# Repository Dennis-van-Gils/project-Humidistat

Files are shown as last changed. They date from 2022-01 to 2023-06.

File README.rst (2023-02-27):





Humidistat
==========
*A Physics of Fluids project.*

This project concerns an Arduino powered controller with a graphical user-interface in Python to regulate the relative humidity inside of a chamber. It does so by controlling two air lines, one with moist air and the other with dry air, using solenoid valves. The temperature, pressure and relative humidity of the chamber and the optional upstream mixing vessel are measured and can be logged over time.

- Github: https://github.com/Dennis-van-Gils/project-Humidistat

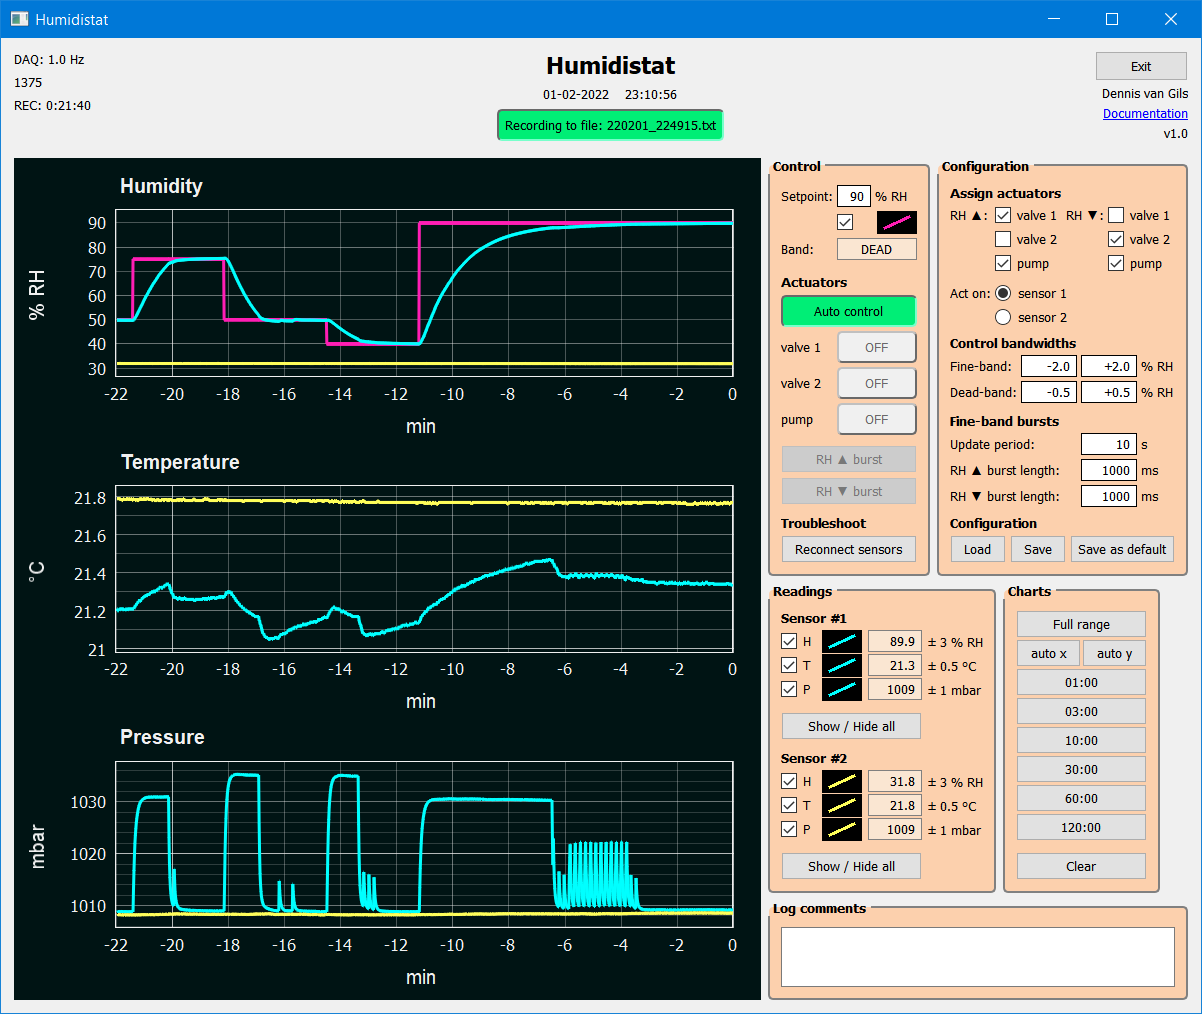
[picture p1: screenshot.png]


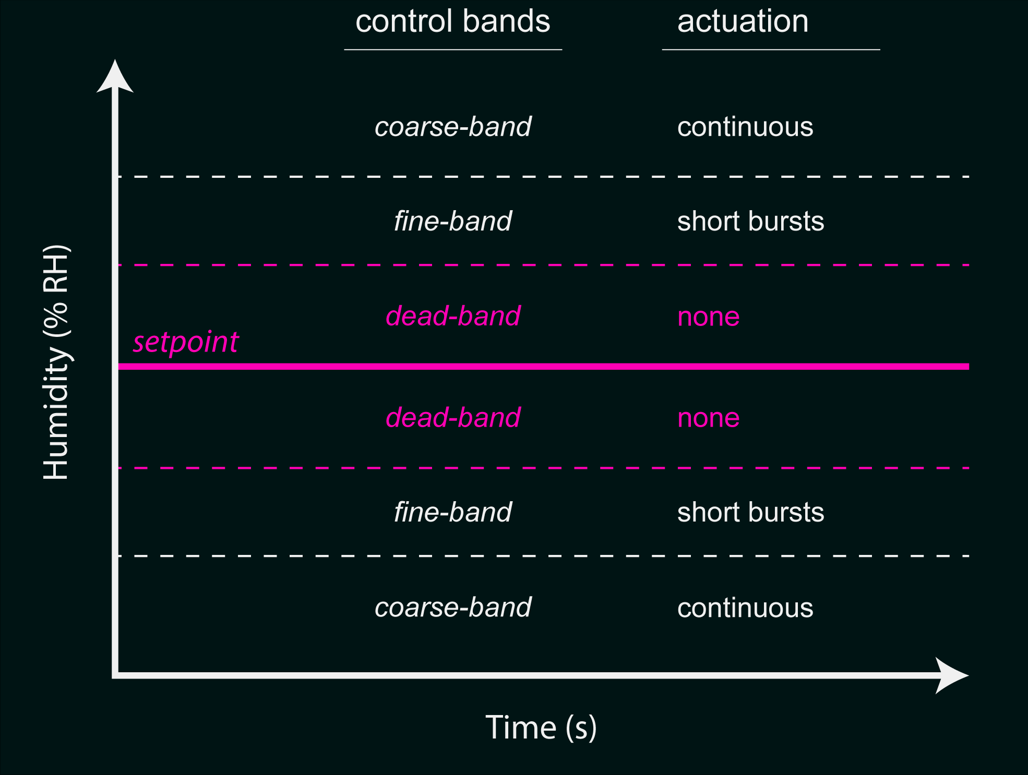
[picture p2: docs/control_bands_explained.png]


Hardware
========
* Adafruit #3857: Adafruit Feather M4 Express - Featuring ATSAMD51 Cortex M4
* Pimoroni PIM472: BME280 Breakout - Temperature, Pressure, Humidity Sensor
* ...

Instructions
============
Download the `latest release <https://github.com/Dennis-van-Gils/project-Humidistat/releases/latest>`_
and unpack to a folder onto your drive.

Flashing the firmware
---------------------

Double click the reset button of the Feather while plugged into your PC. This
will mount a drive called `FEATHERBOOT`. Copy
`src_mcu/_build_Feather_M4/CURRENT.UF2 <https://github.com/Dennis-van-Gils/project-Humidistat/raw/main/src_mcu/_build_Feather_M4/CURRENT.UF2>`_
onto the Featherboot drive. It will restart automatically with the new firmware.

Running the application
-----------------------

Prerequisites
~~~~~~~~~~~~~

| Preferred distribution: Anaconda full or Miniconda

    * `Anaconda <https://www.anaconda.com>`_
    * `Miniconda <https://docs.conda.io/en/latest/miniconda.html>`_

Open `Anaconda Prompt` and navigate to the unpacked folder. Run the following to
install the necessary packages:

::

   cd src_python
   conda update -n base -c defaults conda
   conda create -n humi -c conda-forge  --force -y python=3.8.10
   conda activate humi
   pip install -r requirements.txt

Now you can run the graphical user interface of the humidistat.
In Anaconda prompt:

::

   conda activate humi
   ipython main.py

LED status lights
=================

The RGB LED of the Feather M4 will indicate its status:

* Blue : We're setting up
* Green: All okay and idling

Every read out, the LED will flash brightly turquoise.

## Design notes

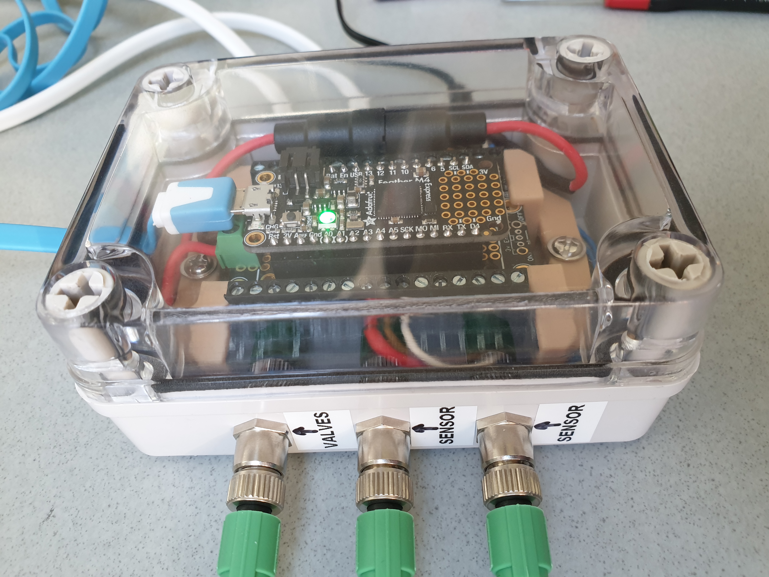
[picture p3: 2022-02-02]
docs/photos/enclosure_2.jpg

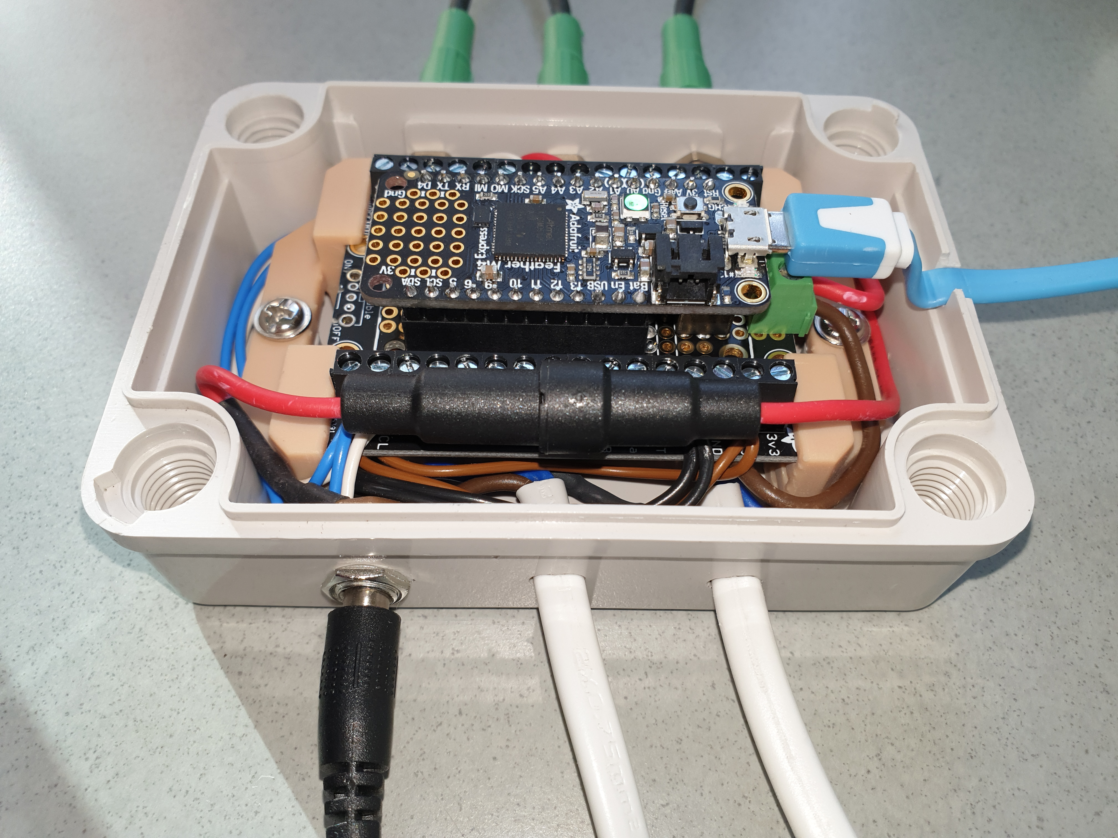
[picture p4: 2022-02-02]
docs/photos/enclosure_4.jpg

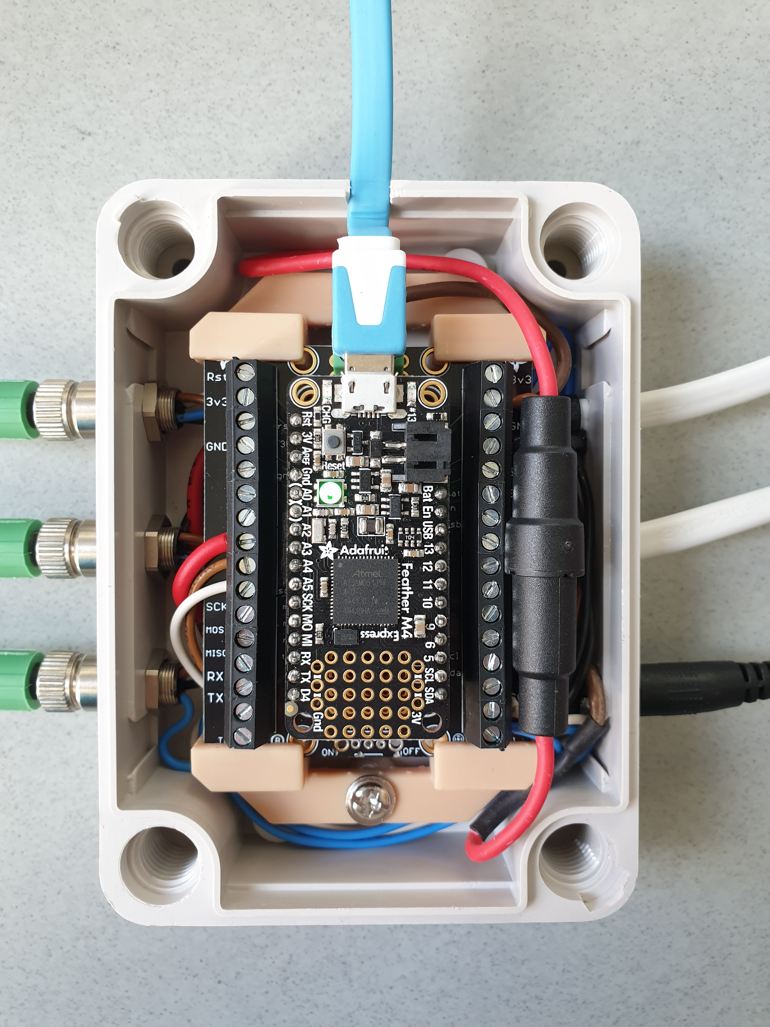
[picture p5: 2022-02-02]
docs/photos/enclosure_3.jpg

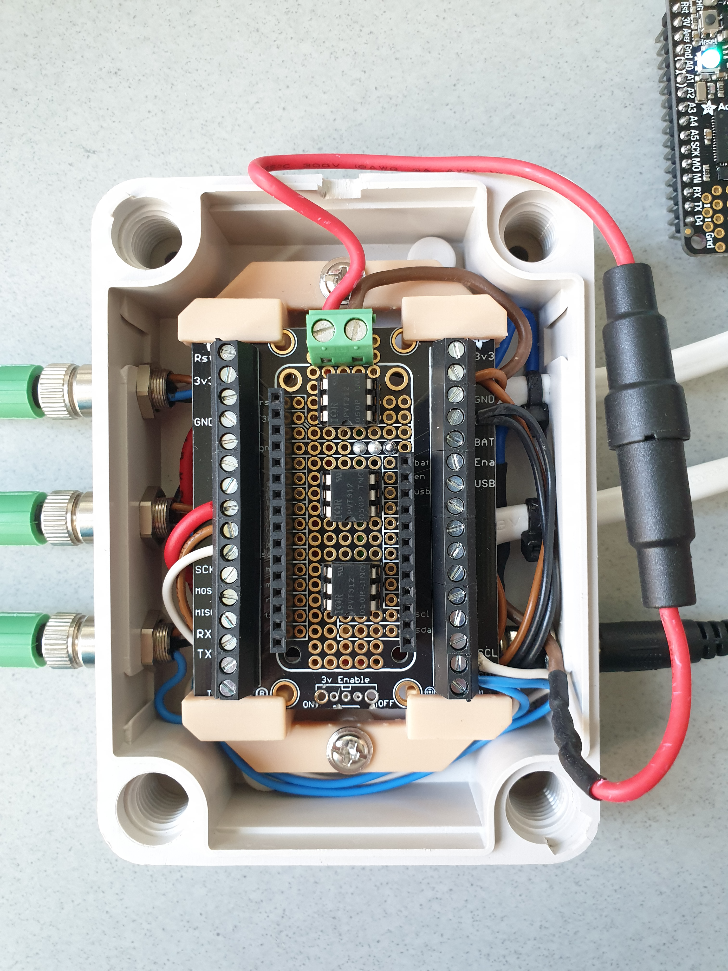
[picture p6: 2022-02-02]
docs/photos/enclosure_5.jpg

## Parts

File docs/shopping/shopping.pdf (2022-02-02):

## Conrad

https://www.conrad.nl/p/hama-00137276-stroom-verlengkabel-wit-300-m-407457

# Farnell

https://nl.farnell.com/bussmann-by-eaton/bk-hht/fuseholder-5a-32v-wire-lead/dp/3650464?ICID=I-RP-STM7REC-0

https://nl.farnell.com/eaton-bussmann-series/s500-200-r/fuse-quick-blow-200ma/dp/1123081?st=fuse%20200ma

https://nl.farnell.com/multicomp/spc15556/dip-socket-6pos-2-54mm-th/dp/2678580?st=dip%20socket

https://nl.farnell.com/infineon/pvt312pbf/relay-photovoltaic/dp/9103899?st=pvt312

https://nl.farnell.com/xp-power/vel18us240-eu-ja/adaptor-ac-dc-24v-0-75a/dp/2643245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

https://nl.farnell.com/phoenix-contact/sacc-e-m-8fs-4con-m8-0-5/sensor-actuator-socket-m8-4pos/dp/2402309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

https://nl.farnell.com/phoenix-contact/sac-4p-m-8ms-3-0-pur/sensor-cord-4p-m8-plug-free-end/dp/2497516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

https://nl.farnell.com/multicomp/mc002825/dc-power-conn-rcpt-2-1mm-0-5a/dp/2908905

https://nl.farnell.com/bridgetek/va-fc-1m-blw/cable-usb-a-to-micro-b-1m-blue/dp/2355196
Flat USB cable

https://nl.farnell.com/phoenix-contact/1729128/terminal-block-wire-to-brd-2pos/dp/3041440?st=screw%20terminal

# Kiwi Electronics

https://www.kiwi-electronics.nl/nl/terminal-block-breakout-featherwing-2348?search=2926

https://www.kiwi-electronics.nl/nl/bme280-breakout-temperature-pressure-humidity-sensor-9901?search=bme280 NOT ON STOCK

# DigiKey

https://punchout.digikey.nl/product-detail/nl/2926/1528-1627-ND/5959339?itemSeq=383666975

https://punchout.digikey.nl/product-detail/nl/PIM472/1778-PIM472-ND/10329004?itemSeq=383667277

# Mouser

https://nl.mouser.com/ProductDetail/Pimoroni/PIM472?qs=sGAEpiMZZMv0NwlthflBi%252B7XhOL0R8%252BMpdUwzgbVFNs%3D

# RS Online

https://nl.rs-online.com/web/p/pneumatic-solenoid-valves/8929993

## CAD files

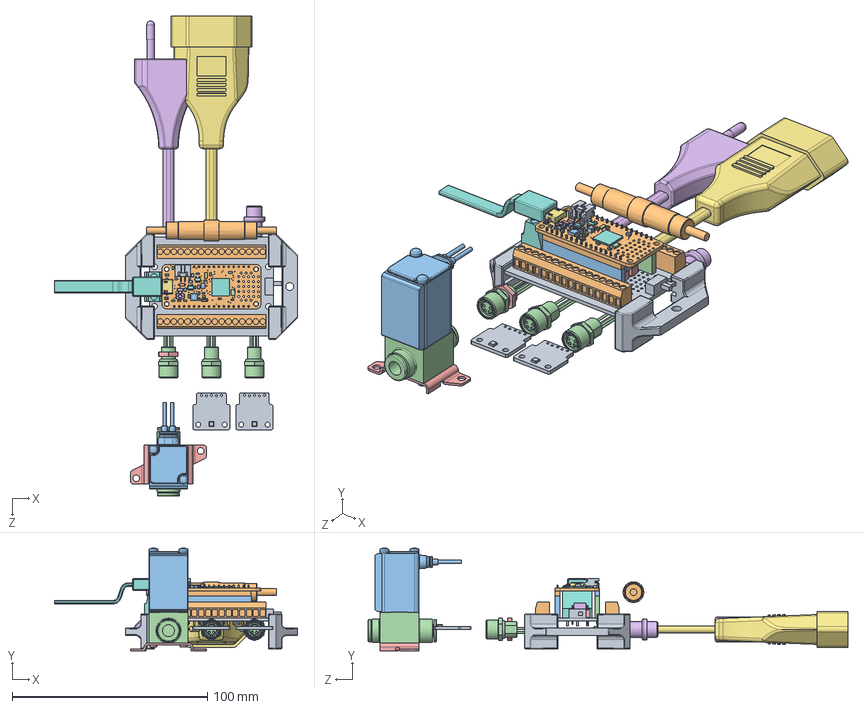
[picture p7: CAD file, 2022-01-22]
Solidworks/_Humidistat_v1_enclosure.SLDASM
124.5 x 52.7 x 245.8 mm
2926 Terminal Block Breakout FeatherWing
screw_terminal_16x_3.5pitch x 2
header_f16_tall
header_f12_tall
dil_socket_2x3 x 3
dil_package_2x3 x 3
resistor_250mW x 3
screw_terminal_3x_large
bracket_tall_3D_printed x 2
Board^PCB Component_3857 Adafruit Feather M4 Express(2)_3857 Adafruit Feather M4 Express
10uF^PCB Component_3857 Adafruit Feather M4 Express(2)_3857 Adafruit Feather M4 Express x 5
1uF^PCB Component_3857 Adafruit Feather M4 Express(2)_3857 Adafruit Feather M4 Express x 15
ORANGE^PCB Component_3857 Adafruit Feather M4 Express(2)_3857 Adafruit Feather M4 Express x 2
KMR2^PCB Component_3857 Adafruit Feather M4 Express(2)_3857 Adafruit Feather M4 Express
microUSB^PCB Component_3857 Adafruit Feather M4 Express(2)_3857 Adafruit Feather M4 Express
MCP73831T-2ACI_OT^PCB Component_3857 Adafruit Feather M4 Express(2)_3857 Adafruit Feather M4 Express x 2
JSTPH^PCB Component_3857 Adafruit Feather M4 Express(2)_3857 Adafruit Feather M4 Express
32.768^PCB Component_3857 Adafruit Feather M4 Express(2)_3857 Adafruit Feather M4 Express
WS2812B3535^PCB Component_3857 Adafruit Feather M4 Express(2)_3857 Adafruit Feather M4 Express
2MB Flash^PCB Component_3857 Adafruit Feather M4 Express(2)_3857 Adafruit Feather M4 Express
MBR120^PCB Component_3857 Adafruit Feather M4 Express(2)_3857 Adafruit Feather M4 Express
DMG341^PCB Component_3857 Adafruit Feather M4 Express(2)_3857 Adafruit Feather M4 Express
100K^PCB Component_3857 Adafruit Feather M4 Express(2)_3857 Adafruit Feather M4 Express
ATSAMD51J^PCB Component_3857 Adafruit Feather M4 Express(2)_3857 Adafruit Feather M4 Express
10uH^PCB Component_3857 Adafruit Feather M4 Express(2)_3857 Adafruit Feather M4 Express
header_m16
header_m12
Phoenix 1500363 x 3
Phoenix 1504071
Europlug_with_cable
Europlug_receptacle_with_cable
USB_cable_flat
PIM472_BME80 x 2
Cooper Bussmann HHT Inline Fuse Holder for 5 x 15 mm, 5 x 20 mm Cartridge Fuse
VDW20GA_VDW Grommet Block
VDW20GA_VDW Body Resin
VDW20GA_VDW Bracket for Resin Body
Multicomp MC002825

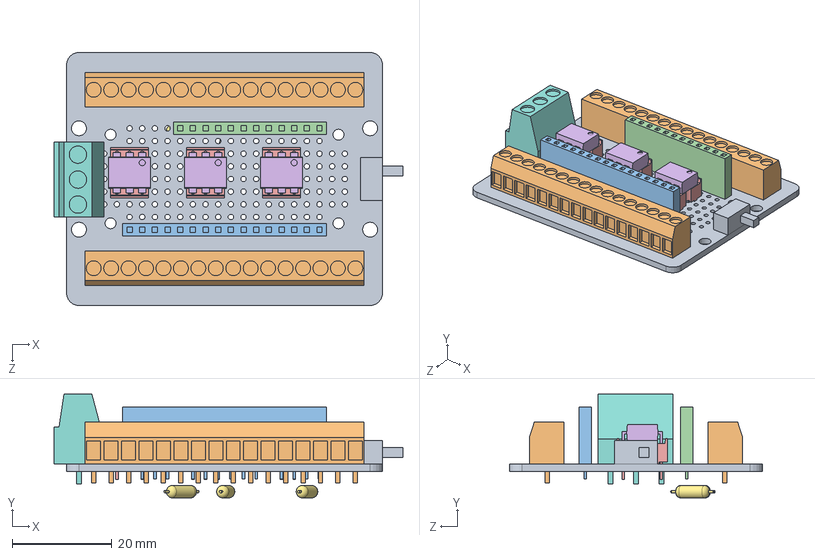
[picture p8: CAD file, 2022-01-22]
Solidworks/2926 Terminal Block Breakout FeatherWing - soldered.SLDASM
70.0 x 20.8 x 50.8 mm
2926 Terminal Block Breakout FeatherWing
screw_terminal_16x_3.5pitch x 2
header_f16_tall
header_f12_tall
dil_socket_2x3 x 3
dil_package_2x3 x 3
resistor_250mW x 3
screw_terminal_3x_large

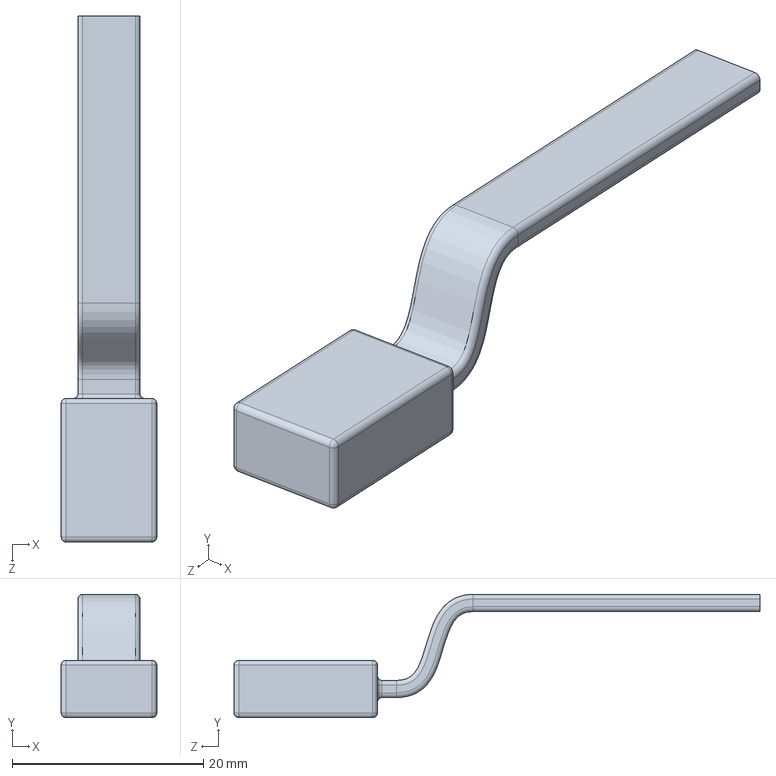
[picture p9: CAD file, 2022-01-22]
Solidworks/USB_cable_flat.SLDPRT
10.0 x 12.9 x 55.0 mm

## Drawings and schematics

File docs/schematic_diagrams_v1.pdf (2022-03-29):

## MS (https://www.bol.com/nl/nl/p/velda-vt-t-tech-luchtpomp-ap-50/9200000011040558/)

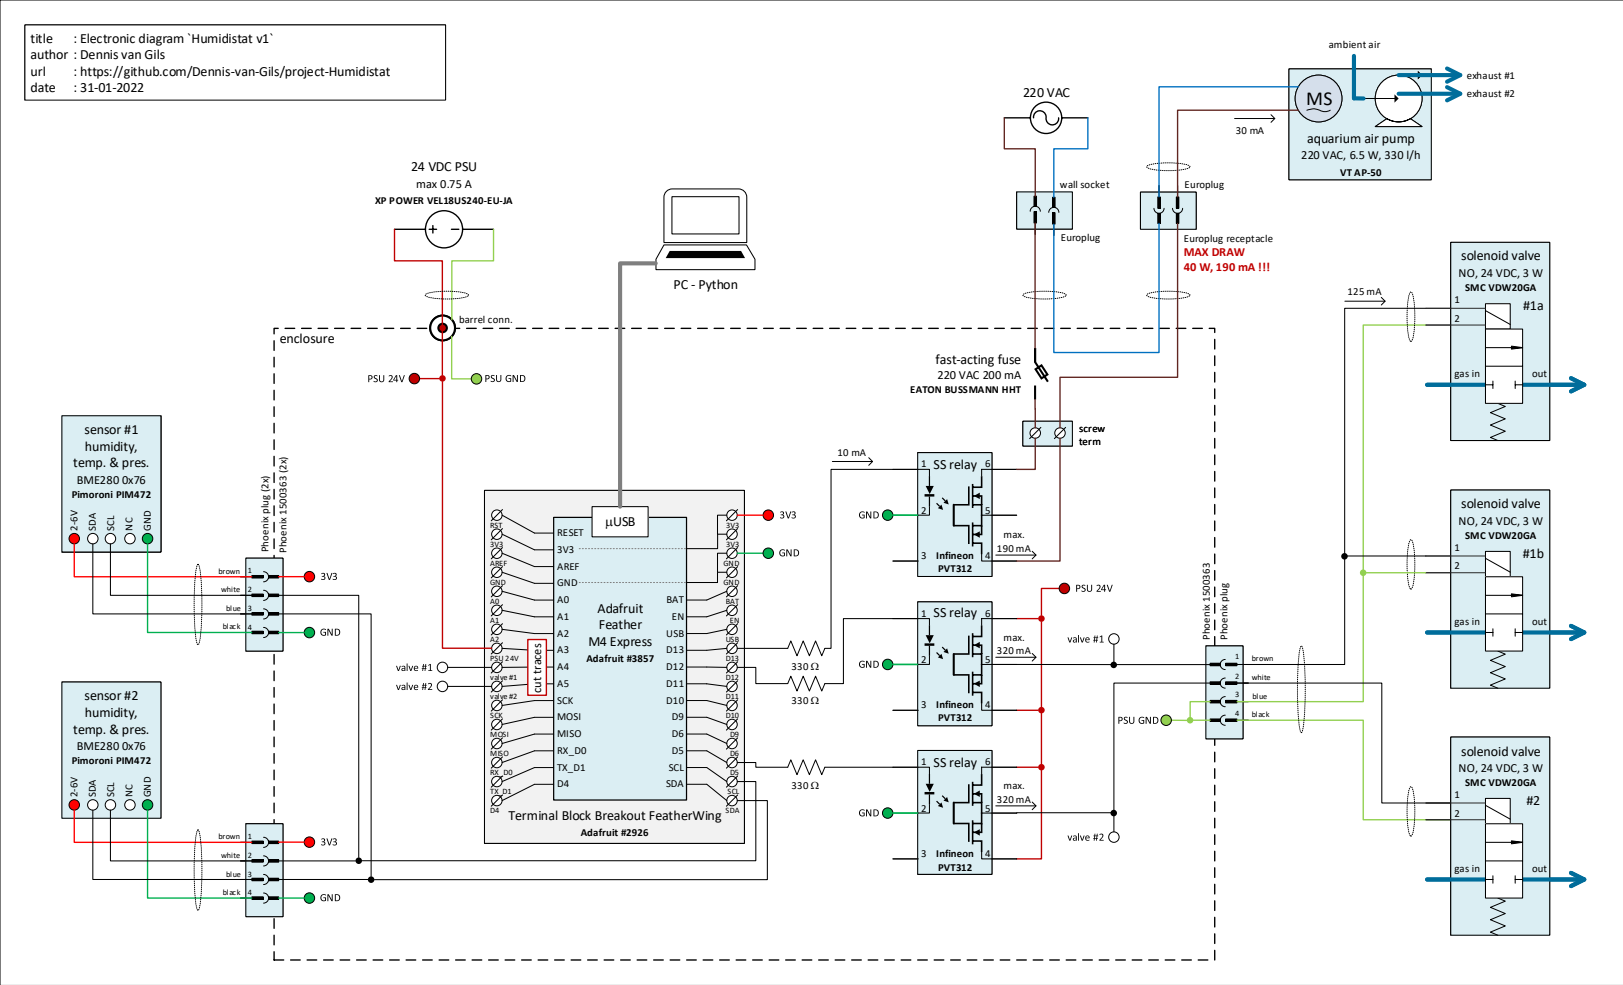
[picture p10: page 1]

author : Dennis van Gils

XP POWER VEL18US240-EU-JA

Terminal Block Breakout FeatherWing

MS

MS

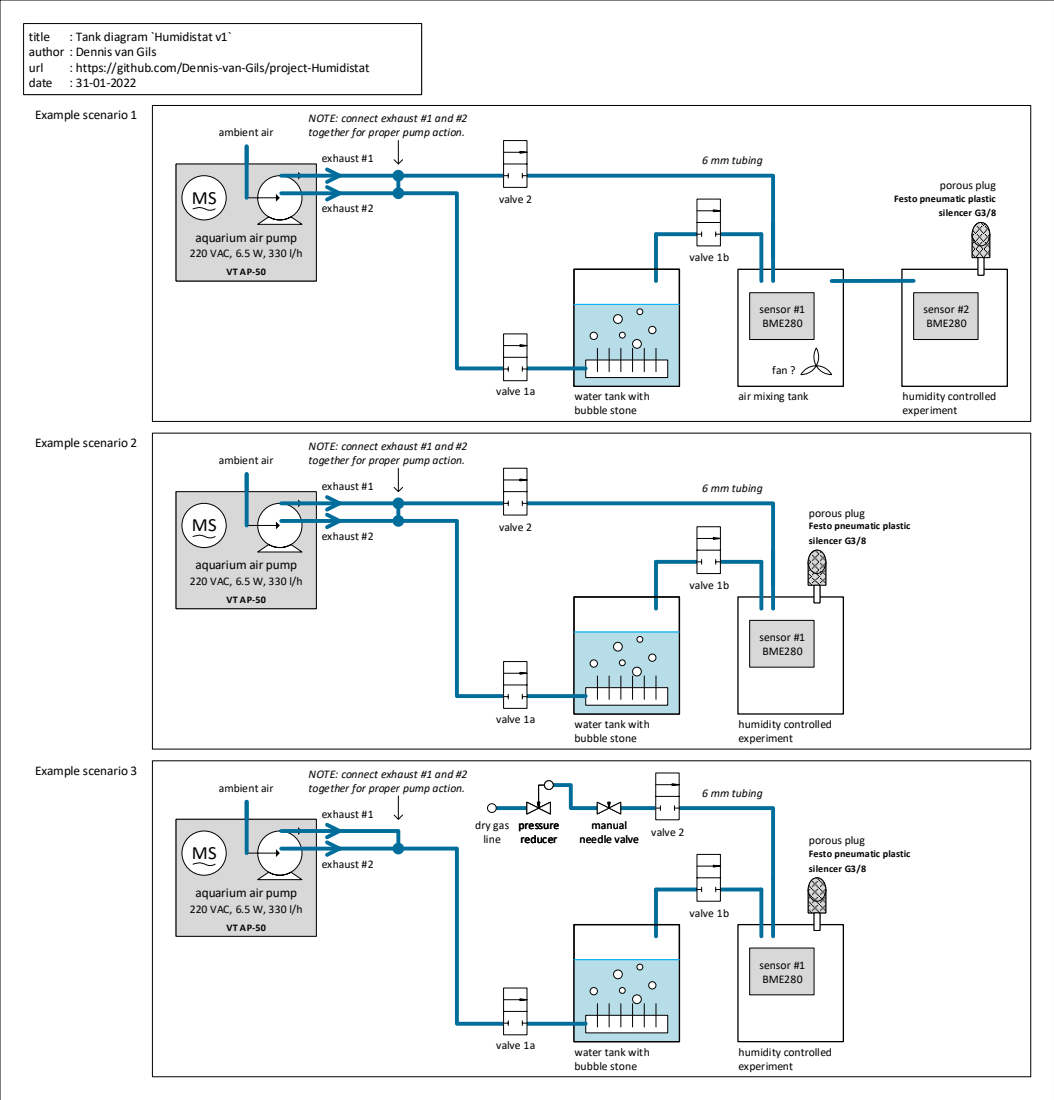
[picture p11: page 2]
valve 1a; air mixing tank; ambient air; sensor #1 BME280; fan ?; humidity controlled experiment; sensor #2 BME280; porous plug; silencer G3/8; 6 mm tubing; valve 1b; exhaust #2; exhaust #1; title; : Tank diagram `Humidistat v1`; url; : https://github.com/Dennis-van-Gils/project-Humidistat; date; valve 2; Example scenario 1; Example scenario 2; Example scenario 3; dry gas line; manual needle valve; pressure reducer

author : Dennis van Gils

NOTE: connect exhaust #1 and #2
together for proper pump action.

Festo pneumatic plastic

aquarium air pump
220 VAC, 6.5 W, 330 l/h

water tank with
bubble stone

porous plug
silencer G3/8

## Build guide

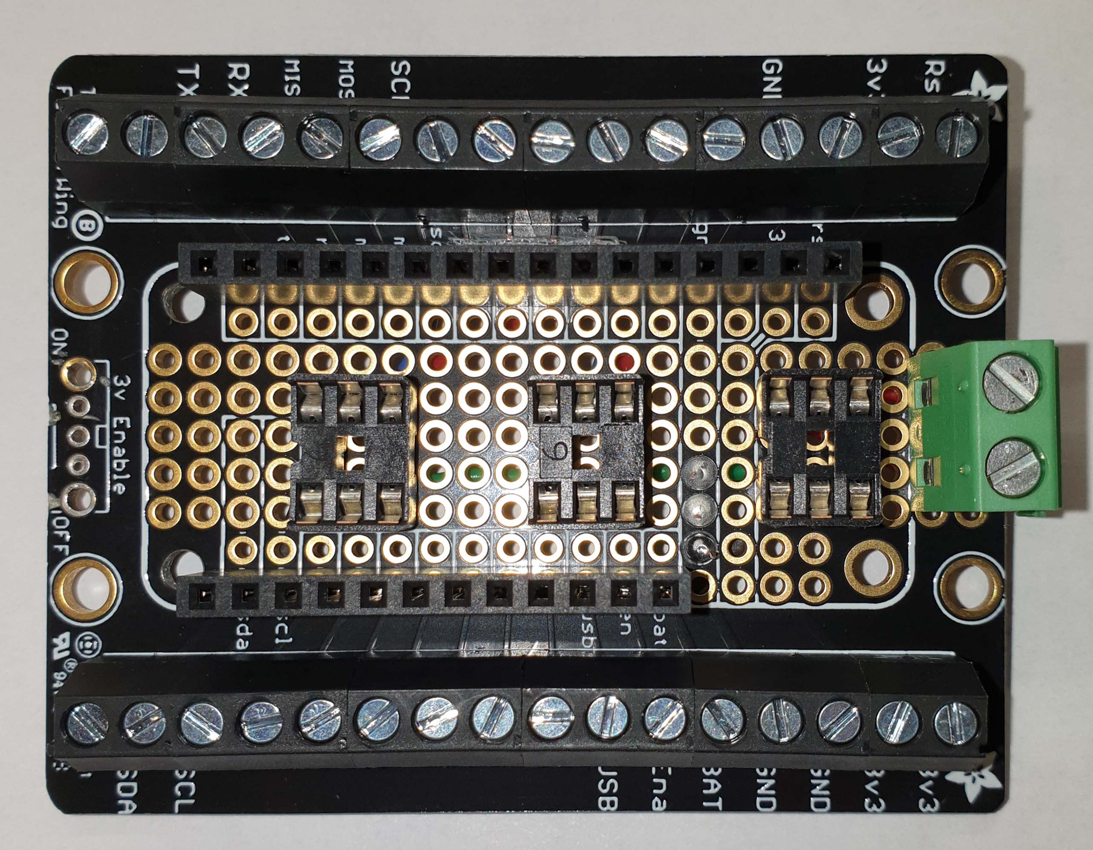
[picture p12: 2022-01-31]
docs/photos/soldering_1.jpg

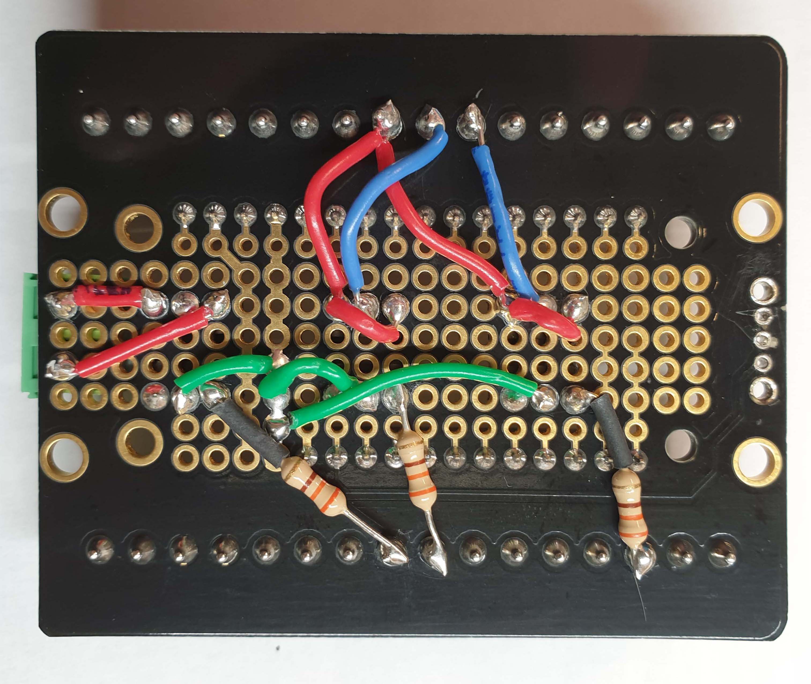
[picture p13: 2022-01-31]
docs/photos/soldering_2.jpg

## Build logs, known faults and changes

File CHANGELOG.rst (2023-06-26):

Changelog
=========

1.2.0 (2023-06-26)
------------------
* Added support for Adafruit Feather M0 Express board

1.1.0 (2022-07-28)
------------------
* Increased significant numbers in temperature and humidity from 1 to 2 digits
* Added time and date information in the header

1.0.0 (2022-02-01)
------------------
* Initial release

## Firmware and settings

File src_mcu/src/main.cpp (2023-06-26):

/*******************************************************************************
  Humidistat v1

  Hardware & pin out
  ------------------

  Adafruit Feather M4 Express
    Sensors:
    - BME280 #1, I2C address 0x76
    - BME280 #2, I2C address 0x77
    Actuators:
    - solenoid valve #1    , via solid-state relay on pin D12
    - solenoid valve #2    , via solid-state relay on pin D5
    - external 220 VAC pump, via solid-state relay on pin D13

  The RGB LED of the Feather M4 will indicate its status:
    - Blue : We're setting up
    - Green: All okay and idling
  Every read out, the LED will flash brightly turquoise.

  The Arduino will autonomously read out the sensor data at fixed time intervals
  and will report these readings over serial.

  https://github.com/Dennis-van-Gils/project-Humidistat
  Dennis van Gils
  26-06-2023
*******************************************************************************/

#include <Arduino.h>
#include <SPI.h>
#include <Wire.h>

#include "Adafruit_BME280.h"
#include "Adafruit_NeoPixel.h"
#include "Adafruit_Sensor.h"
#include "DvG_SerialCommand.h"

// Pin assignments for actuators
#define PIN_VALVE_1 12
#define PIN_VALVE_2 5
#define PIN_PUMP 13

// Figure out which Adafruit board is being used: M0 or M4
#if defined _VARIANT_ARDUINO_ZERO_
#  define HAS_NEOPIXEL 0
#elif defined _VARIANT_FEATHER_M4_
#  define HAS_NEOPIXEL 1
#endif

// BME280: Temperature, humidity and pressure sensors
// NOTE: Do not read out faster than once per second as per BME280 spec-sheet.
#define DAQ_PERIOD 1000 // [ms] Data-acquisition period
Adafruit_BME280 bme_1;
Adafruit_BME280 bme_2;

#if HAS_NEOPIXEL == 1
// On-board NeoPixel RGB LED
#  define NEO_DIM 3    // Brightness level for dim intensity [0 -255]
#  define NEO_BRIGHT 6 // Brightness level for bright intensity [0 - 255]
#  define NEO_FLASH_DURATION 100 // [ms]
bool neo_flash = false;
uint32_t t_neo_flash = 0;
Adafruit_NeoPixel neo(1, PIN_NEOPIXEL, NEO_GRB + NEO_KHZ800);
#endif

// Serial command listener
DvG_SerialCommand sc(Serial);

// -----------------------------------------------------------------------------
//  State control
// -----------------------------------------------------------------------------

struct State {
  /* Holds actual actuator states and sensor readings
   */
  bool valve_1 = false;
  bool valve_2 = false;
  bool pump = false;
  float temp_1 = NAN; // ['C]
  float temp_2 = NAN; // ['C]
  float humi_1 = NAN; // [% RH]
  float humi_2 = NAN; // [% RH]
  float pres_1 = NAN; // [Pa]
  float pres_2 = NAN; // [Pa]
};
State state;

struct Request {
  /* Holds requested actuator states
   */
  bool valve_1 = false;
  bool valve_2 = false;
  bool pump = false;
};
Request request;

void connect_BME280_sensors() {
  uint8_t idx_try;
  bool success;

  for (idx_try = 0; idx_try < 3; idx_try++) {
    success = bme_1.begin(0x76);
    if (success) {
      break;
    }
    delay(1000);
  }
  if (!success) {
    Serial.println("Could not find BME280 sensor #1");
  }

  for (idx_try = 0; idx_try < 3; idx_try++) {
    success = bme_2.begin(0x77);
    if (success) {
      break;
    }
    delay(1000);
  }
  if (!success) {
    Serial.println("Could not find BME280 sensor #2");
  }
}

void read_BME280_sensors() {
  /* Update the sensor readings and save in `state`.
  NOTE: Do not read out faster than once per second as per BME280 spec-sheet.
   */
  state.temp_1 = bme_1.readTemperature();
  state.humi_1 = bme_1.readHumidity();
  state.pres_1 = bme_1.readPressure();

  state.temp_2 = bme_2.readTemperature();
  state.humi_2 = bme_2.readHumidity();
  state.pres_2 = bme_2.readPressure();
}

void report(uint32_t now, uint32_t t_0) {
  // Report `state` over serial
  Serial.print(now - t_0);
  Serial.write('\t');
  Serial.print(state.valve_1);
  Serial.write('\t');
  Serial.print(state.valve_2);
  Serial.write('\t');
  Serial.print(state.pump);
  Serial.write('\t');
  Serial.print(state.humi_1, 2);
  Serial.write('\t');
  Serial.print(state.humi_2, 2);
  Serial.write('\t');
  Serial.print(state.temp_1, 2);
  Serial.write('\t');
  Serial.print(state.temp_2, 2);
  Serial.write('\t');
  Serial.print(state.pres_1, 0);
  Serial.write('\t');
  Serial.print(state.pres_2, 0);
  Serial.write('\n');
}

void measure_and_report(uint32_t now, uint32_t t_0) {
  /* Perform a single measurement, update `state` and report over serial.
   */

#if HAS_NEOPIXEL == 1
  // Set RGB LED to bright turquoise: Performing new measurement
  neo_flash = true;
  t_neo_flash = now;
  neo.setPixelColor(0, neo.Color(0, NEO_BRIGHT, NEO_BRIGHT));
  neo.show();
#endif

  read_BME280_sensors();
  report(now, t_0);
}

bool parseBoolInString(char *strIn, uint8_t iPos) {
  if (strlen(strIn) > iPos) {
    return (strncmp(&strIn[iPos], "1", 1) == 0);
  } else {
    return false;
  }
}

int parseIntInString(char *strIn, uint8_t iPos) {
  if (strlen(strIn) > iPos) {
    return atoi(&strIn[iPos]);
  } else {
    return 0;
  }
}

// -----------------------------------------------------------------------------
//  setup
// -----------------------------------------------------------------------------

void setup() {
  // Initialize actuators
  pinMode(PIN_VALVE_1, OUTPUT);
  pinMode(PIN_VALVE_2, OUTPUT);
  pinMode(PIN_PUMP, OUTPUT);
  digitalWrite(PIN_VALVE_1, state.valve_1);
  digitalWrite(PIN_VALVE_2, state.valve_2);
  digitalWrite(PIN_PUMP, state.pump);

#if HAS_NEOPIXEL == 1
  // Set RGB LED to blue: We're setting up
  neo.begin();
  neo.setPixelColor(0, neo.Color(0, 0, NEO_BRIGHT));
  neo.show();
#endif

  Serial.begin(9600);

  connect_BME280_sensors();
  read_BME280_sensors(); // Ditch the first reading. Tends to be off.

#if HAS_NEOPIXEL == 1
  // Set RGB LED to dim green: We're all ready to go and idle
  neo.setPixelColor(0, neo.Color(0, NEO_DIM, 0));
  neo.show();
#endif
}

// -----------------------------------------------------------------------------
//  loop
// -----------------------------------------------------------------------------

void loop() {
  char *str_cmd; // Incoming serial command string
  uint32_t now = millis();
  static uint32_t t_0 = now;
  static uint32_t tick = now;

  // Short burst control
  static bool burst = false;   // Burst in progress?
  static uint32_t T_burst = 0; // [ms] Length of burst
  static uint32_t t_burst = 0; // `millis()` start of burst

  // Process incoming serial commands
  if (sc.available()) {
    str_cmd = sc.getCmd();

    if (strcmp(str_cmd, "id?") == 0) {
      Serial.println("Arduino, Humidistat v1");

    } else if (strncmp(str_cmd, "a", 1) == 0) {
      // Request new actuator states all at once
      // Command parameters:
      //  "a"[0/1: valve_1?][0/1: valve_2?][0/1: pump?]
      //   E.g: "a101" to open valve_1, close valve_2 and enable the pump
      request.valve_1 = parseBoolInString(str_cmd, 1);
      request.valve_2 = parseBoolInString(str_cmd, 2);
      request.pump = parseBoolInString(str_cmd, 3);

    } else if (strncmp(str_cmd, "b", 1) == 0) {
      // `Burst` mode: Request open valve 1 and/or valve 2 and/or the pump for a
      // short fixed time duration. Closes all again after the elapsed time.
      // Command parameters:
      //  "b"[0/1: valve_1?][0/1: valve_2?][0/1: pump?][int: duration in ms]
      //   E.g: "b101500" to open valve_1 and the pump for 500 ms
      request.valve_1 = parseBoolInString(str_cmd, 1);
      request.valve_2 = parseBoolInString(str_cmd, 2);
      request.pump = parseBoolInString(str_cmd, 3);
      T_burst = parseIntInString(str_cmd, 4);
      t_burst = now;
      burst = true;

    } else if (strncmp(str_cmd, "v1", 2) == 0) {
      // Turn valve 1 on/off
      request.valve_1 = parseBoolInString(str_cmd, 2);

    } else if (strncmp(str_cmd, "v2", 2) == 0) {
      // Turn valve 2 on/off
      request.valve_2 = parseBoolInString(str_cmd, 2);

    } else if (strncmp(str_cmd, "p", 1) == 0) {
      // Turn pump on/off
      request.pump = parseBoolInString(str_cmd, 1);

    } else if (strcmp(str_cmd, "r") == 0) {
      // Try to reconnect to BME280's
      connect_BME280_sensors();
    }
  }

  // Request to turn off actuators at end of burst
  if (burst && (now - t_burst >= T_burst)) {
    burst = false;
    request.valve_1 = false;
    request.valve_2 = false;
    request.pump = false;
  }

  // Grant all requested actuator states
  bool change_detected = false;
  if (request.valve_1 != state.valve_1) {
    state.valve_1 = request.valve_1;
    digitalWrite(PIN_VALVE_1, state.valve_1);
    change_detected = true;
  }
  if (request.valve_2 != state.valve_2) {
    state.valve_2 = request.valve_2;
    digitalWrite(PIN_VALVE_2, state.valve_2);
    change_detected = true;
  }
  if (request.pump != state.pump) {
    state.pump = request.pump;
    digitalWrite(PIN_PUMP, state.pump);
    change_detected = true;
  }

  // Report immediately over serial when actuators have changed state
  if (change_detected) {
    report(now, t_0);
  }

  // DAQ
  if (now - tick >= DAQ_PERIOD) {
    tick += DAQ_PERIOD; // Strict-interval time keeping
    measure_and_report(now, t_0);
  }

#if HAS_NEOPIXEL == 1
  // Set RGB LED back to dim green: Measurement is done
  if (neo_flash && (now - t_neo_flash >= NEO_FLASH_DURATION)) {
    neo_flash = false;
    neo.setPixelColor(0, neo.Color(0, NEO_DIM, 0));
    neo.show();
  }
#endif
}

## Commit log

2022-01-22 Initial commit
    Continuation of deprecated repo `project-humidity-controller`
    [2926 Terminal Block Breakout FeatherWing - soldered.SLDASM, USB_cable_flat.SLDPRT, _Humidity_controller_enclosure.SLDASM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]
2022-01-22 In progress: actuator settings
    [gui.xlsx]
2022-01-23 Testing: short burst control
    [main.cpp]
2022-01-23 Idea for 3rd valve and air fan
2022-01-24 In progress: automatic control
    [gui.xlsx]
2022-01-24 In progress: wiring up GUI
2022-01-25 Wired up more GUI controls
2022-01-25 Improved 'burst' control, allowing different actuators to be set at once.
2022-01-25 Added max. currents
2022-01-28 Keep GUI open when Arduino is not detected
2022-01-28 Improved top frame
2022-01-31 Update schematics
2022-01-31 Updated schematics
2022-02-01 Squashed commit of the following:
    commit 55e38d07a96c6cf900572147fb922a7955fc6669
    Author: Dennis-van-Gils <vangils.dennis@gmail.com>
    Date: Tue Feb 1 22:06:50 2022 +0100
    Bump dependence `dvg-devices~=1.1`
    commit 9c26cb40b4028857181d839634dd572701e061cd
    Author: Dennis-van-Gils <vangils.dennis@gmail.com>
    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
    [gui.xlsx]
2022-02-02 TODO: Fix wrong `capacity` calculation of history charts
2022-02-02 Shopping list
    [shopping.xlsx]
2023-06-26 Added support for Adafruit Feather M0 board

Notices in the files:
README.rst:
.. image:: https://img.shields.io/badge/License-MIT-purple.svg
